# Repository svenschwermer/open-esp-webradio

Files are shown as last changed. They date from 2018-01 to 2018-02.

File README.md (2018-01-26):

# Open ESP Webradio
This project aims to build a webradio based on the ESP8266. The goal is to make
it controllable via touchscreen.

_This respository and the entire project is very much work-in-progress…_

## Hardware
The incoming encoded audio stream is buffered in an external SPI RAM. The ESP8266
has two hardware SPI controllers: SPI0 (aka SPI) and SPI1 (aka HSPI). The ESP-12F
module that is used here uses SPI0 for accessing the SPI flash memory that holds
the program data. Here, HSPI is used for accessing the SPI RAM. Since the pins
that are regularly used for HSPI will be used for talking I2S to the audio DAC,
SPI0 and HSPI are configured in overlap mode. That means, that they share the same
pins (except for the CS line). There is an arbiter that selects which SPI controller
gets to access the pins. The SPI RAM device here is a 23LC1024 which has a capacity
of 1 Mbit. Both the ESP8266 and the 23LC1024 support Quad SPI where all data lines
(SIO0..3) are bidirectional, so 4 bits are transferred in every clock cycle.

The audio DAC that is used here is the WM8731. The audio data is transferred using
I2S via the I2S controller that is built into the ESP8266. The configuration of
the DAC is performed via I2C. Even though the ESP8266 contains an I2C controller,
it is not used here, because the pins were not available. Since the WM8731 comes
with a microphone interface, it is included together with the reverse I2S direction.

The display that is used here, is a MI0283QT 240x320 color LCD. Infos about the
adapter board that molds a touchscreen controller as well, can be found
[here](https://github.com/watterott/MI0283QT-Adapter). Both the LCD controller and
the touchscreen controller are also sharing the same SPI pins as the SPI flash and
the SPI RAM. Both are controlled by the HSPI controller. The LCD uses a hardware
CS, but for the touchscreen controller, there was no more hardware CS available
that is not used for anything else. Hence, GPIO16 is used as the CS line for the
touchscreen controller.

### Schematic
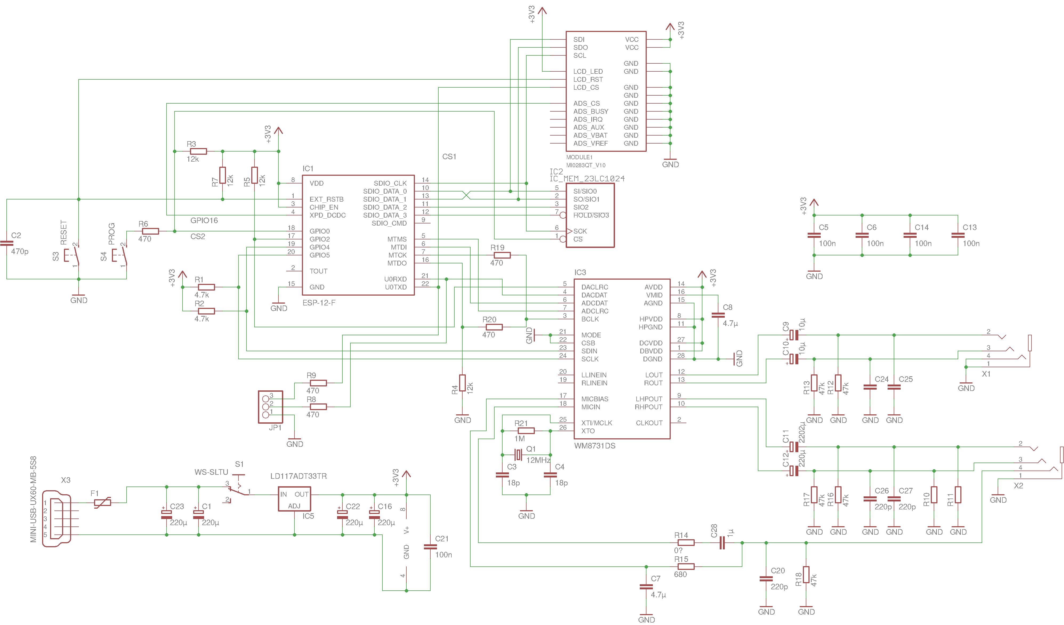
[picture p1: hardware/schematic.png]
MI0283QT-Adapter


#### Remarks
- The SPI RAM is wired incorrectly: SIO2 and SIO3 should be swapped. This is
  fixed in software.

## Software
To build the software, follow the instructions in the
[open-esp-webradio repository](https://github.com/SuperHouse/esp-open-rtos) to
install the required toolchain. Then simply run `make` or `make flash`,
respectively, to compile or flash the image. The WiFi credentials should be
supplied via the file `./esp-open-rtos/include/private_ssid_config.h`.

## Credits
Inspired by [ESP8266_MP3_DECODER](https://github.com/espressif/ESP8266_MP3_DECODER),
this project builds upon the following components:
- [open-esp-webradio](https://github.com/SuperHouse/esp-open-rtos)
- [libmad](https://www.underbit.com/products/mad)

## License
This project is licensed under the terms of the GNU GPLv3, see [LICENSE.md](LICENSE.md).

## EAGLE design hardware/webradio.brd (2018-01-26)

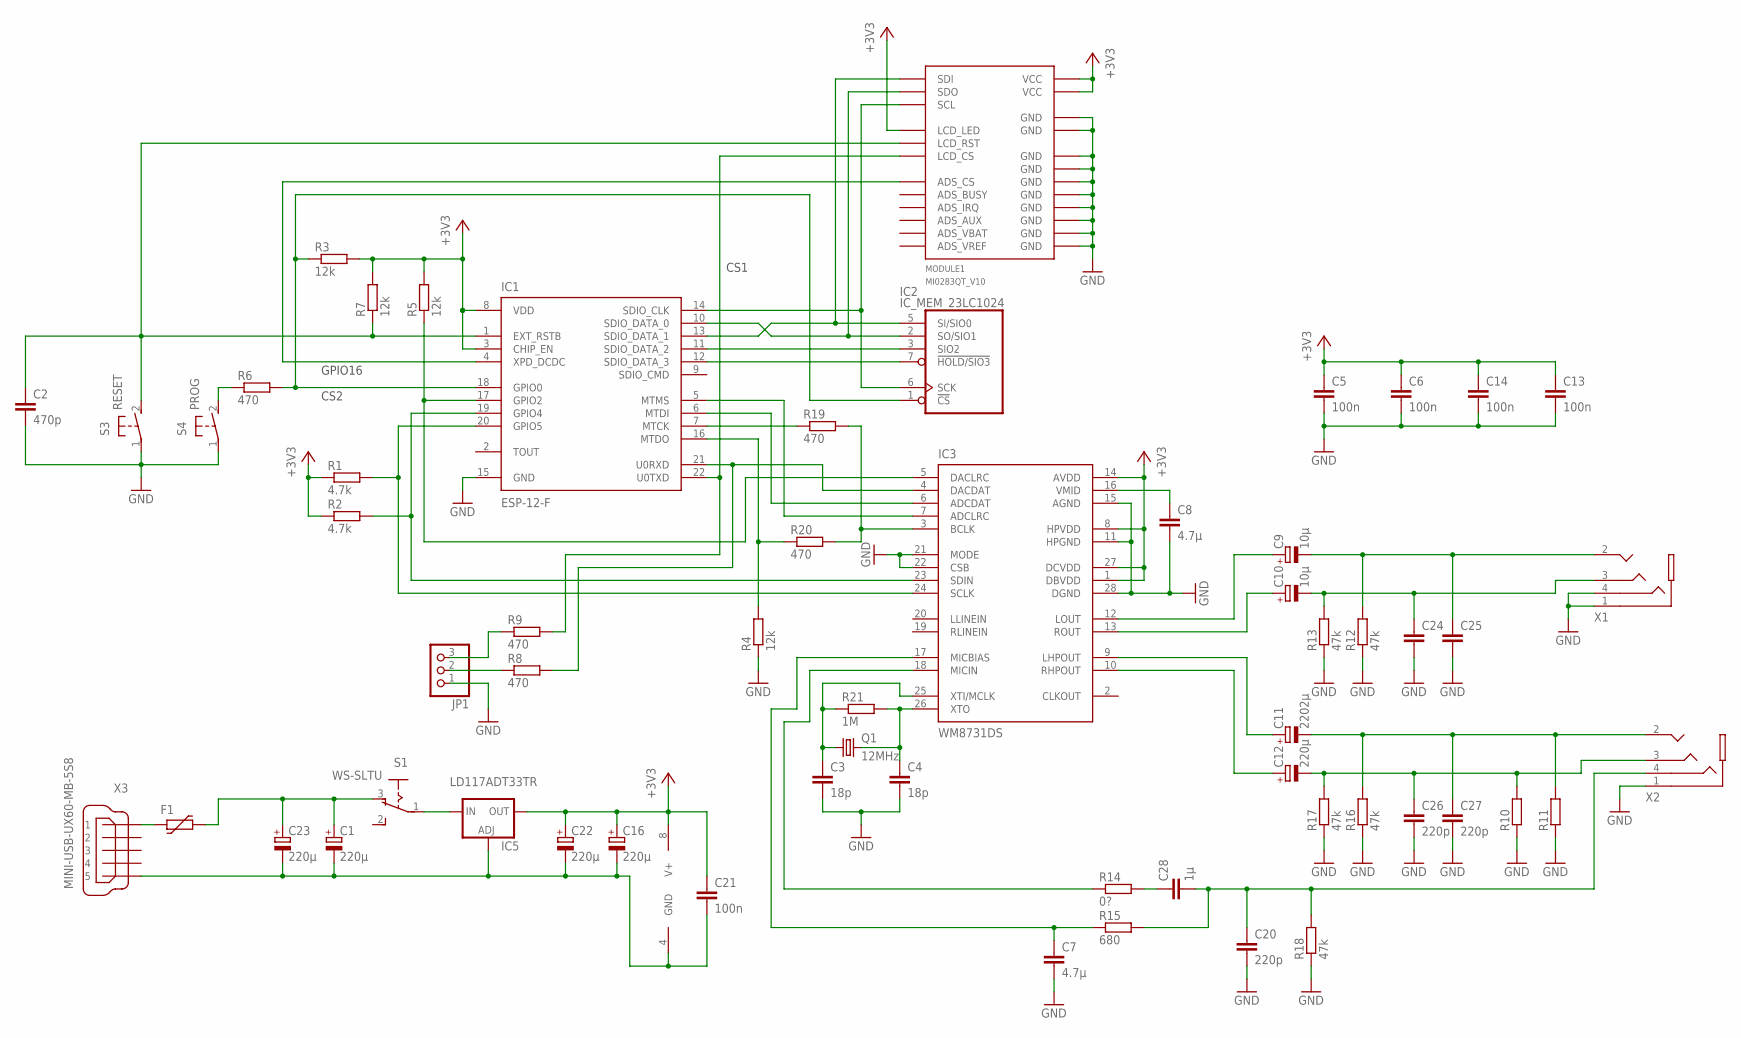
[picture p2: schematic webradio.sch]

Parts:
C1, C16, C22, C23: 220µ; B/3528-21R
C2: 470p; C0805
C3, C4: 18p; C0805
C5, C6, C13, C14, C21: 100n; C0805
C7, C8: 4.7µ; C0805
C9, C10: 10µ; A/3216-18R
C11: 2202µ; D/7343-31R
C12: 220µ; D/7343-31R
C20, C26, C27: 220p; C0805
C24, C25: C-EUC0805; C0805
C28: 1µ; C0805
F1: FUSE_PTC-1812; PTC1812L
IC1: ESP-12-F
IC2: IC_MEM_23LC1024; SOIC-8
IC3: WM8731DS; SSOP28
IC5: LD117ADT33TR; DPACK
JP1: PINHD-1X3/90; 1X03/90
MODULE1: MI0283QT_V10
Q1: 12MHz; HC49UP
R1, R2: 4.7k; R0805
R3, R4, R5, R7: 12k; R0805
R6, R8, R9, R19, R20: 470; R0805
R10, R11: R-EU_R0805; R0805
R12, R13, R16, R17, R18: 47k; R0805
R14: 0?; R0805
R15: 680; R0805
R21: 1M; R0805
S1: WS-SLTU; 450302014072
S3: RESET; B3F-31XX
S4: PROG; B3F-31XX
X1, X2: SJ-43514-SMT
X3: MINI-USB-UX60-MB-5S8; UX60-MB-5S8

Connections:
+3V3: C5.1, C6.1, C13.1, C14.1, C16.+, C21.1, C22.+, IC1.3 (CHIP_EN), IC1.8 (VDD), IC2.8 (V+), IC3.1 (DBVDD), IC3.8 (HPVDD), IC3.14 (AVDD), IC3.27 (DCVDD), IC5.4 (OUT), MODULE1.3_VCC (VCC), MODULE1.4_VCC (VCC), MODULE1.5_LCD_LED (LCD_LED), R1.1, R2.1, R3.2, R5.2, R7.2
GND: C1.-, C2.2, C3.2, C4.2, C5.2, C6.2, C7.2, C8.2, C13.2, C14.2, C16.-, C20.2, C21.2, C22.-, C23.-, C24.2, C25.2, C26.2, C27.2, IC1.15 (GND), IC2.4 (GND), IC3.11 (HPGND), IC3.15 (AGND), IC3.21 (MODE), IC3.22 (CSB), IC3.28 (DGND), IC5.1 (ADJ), JP1.1, MODULE1.1_GND (GND), MODULE1.2_GND (GND), MODULE1.GND_1 (GND), MODULE1.GND_2 (GND), MODULE1.GND_3 (GND), MODULE1.GND_4 (GND), MODULE1.GND_5 (GND), MODULE1.GND_6 (GND), MODULE1.GND_7 (GND), MODULE1.GND_8 (GND), R4.1, R10.1, R11.1, R12.1, R13.1, R16.1, R17.1, R18.1, S3.1, S4.1, X1.1, X1.4, X2.1, X3.5
unnamed: IC1.14 (SDIO_CLK), IC2.6 (SCK), MODULE1.10_SCL (SCL)
unnamed: IC1.18 (GPIO0), IC2.1 (!CS), R3.1, R6.2
unnamed: F1.1, X3.1
unnamed: IC1.10 (SDIO_DATA_0), IC2.2 (SO/SIO1), MODULE1.9_SDO (SDO)
unnamed: IC1.11 (SDIO_DATA_2), IC2.3 (SIO2)
unnamed: IC1.12 (SDIO_DATA_3), IC2.7 (!HOLD/SIO3)
unnamed: IC1.16 (MTDO), R4.2, R20.1
unnamed: IC1.21 (U0RXD), IC3.4 (DACDAT), R8.2
unnamed: IC1.17 (GPIO2), IC3.5 (DACLRC), R5.1
unnamed: IC1.19 (GPIO4), IC3.23 (SDIN), R2.2
unnamed: IC1.20 (GPIO5), IC3.24 (SCLK), R1.2
unnamed: R6.1, S4.2 (S)
unnamed: JP1.2, R8.1
unnamed: C2.1, IC1.1 (EXT_RSTB), MODULE1.6_LCD_RST (LCD_RST), R7.1, S3.2 (S)
unnamed: IC1.22 (U0TXD), MODULE1.7_LCD_CS (LCD_CS), R9.2
unnamed: JP1.3, R9.1
unnamed: C3.1, IC3.25 (XTI/MCLK), Q1.1, R21.1
unnamed: C4.1, IC3.26 (XTO), Q1.2, R21.2
unnamed: C1.+, C23.+, F1.2, S1.3 (O)
unnamed: C8.1, IC3.16 (VMID)
unnamed: C10.+, IC3.13 (ROUT)
unnamed: C9.+, IC3.12 (LOUT)
unnamed: C9.-, C25.1, R12.2, X1.2
unnamed: C10.-, C24.1, R13.2, X1.3
unnamed: C12.+, IC3.10 (RHPOUT)
unnamed: C11.+, IC3.9 (LHPOUT)
unnamed: C11.-, C27.1, R11.2, R16.2, X2.2
unnamed: C12.-, C26.1, R10.2, R17.2, X2.3
unnamed: IC5.3 (IN), S1.1
unnamed: C7.1, IC3.17 (MICBIAS), R15.1
unnamed: IC3.18 (MICIN), R14.1
unnamed: C28.1, R14.2
unnamed: C20.1, C28.2, R15.2, R18.2, X2.4
unnamed: IC1.6 (MTDI), IC3.6 (ADCDAT)
unnamed: IC1.5 (MTMS), IC3.7 (ADCLRC)
unnamed: IC1.7 (MTCK), R19.1
unnamed: IC3.3 (BCLK), R19.2, R20.2
unnamed: IC1.13 (SDIO_DATA_1), IC2.5 (SI/SIO0), MODULE1.8_SDI (SDI)
unnamed: IC1.4 (XPD_DCDC), MODULE1.11_ADS_CS (ADS_CS)

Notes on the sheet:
CS1
CS2
GPIO16

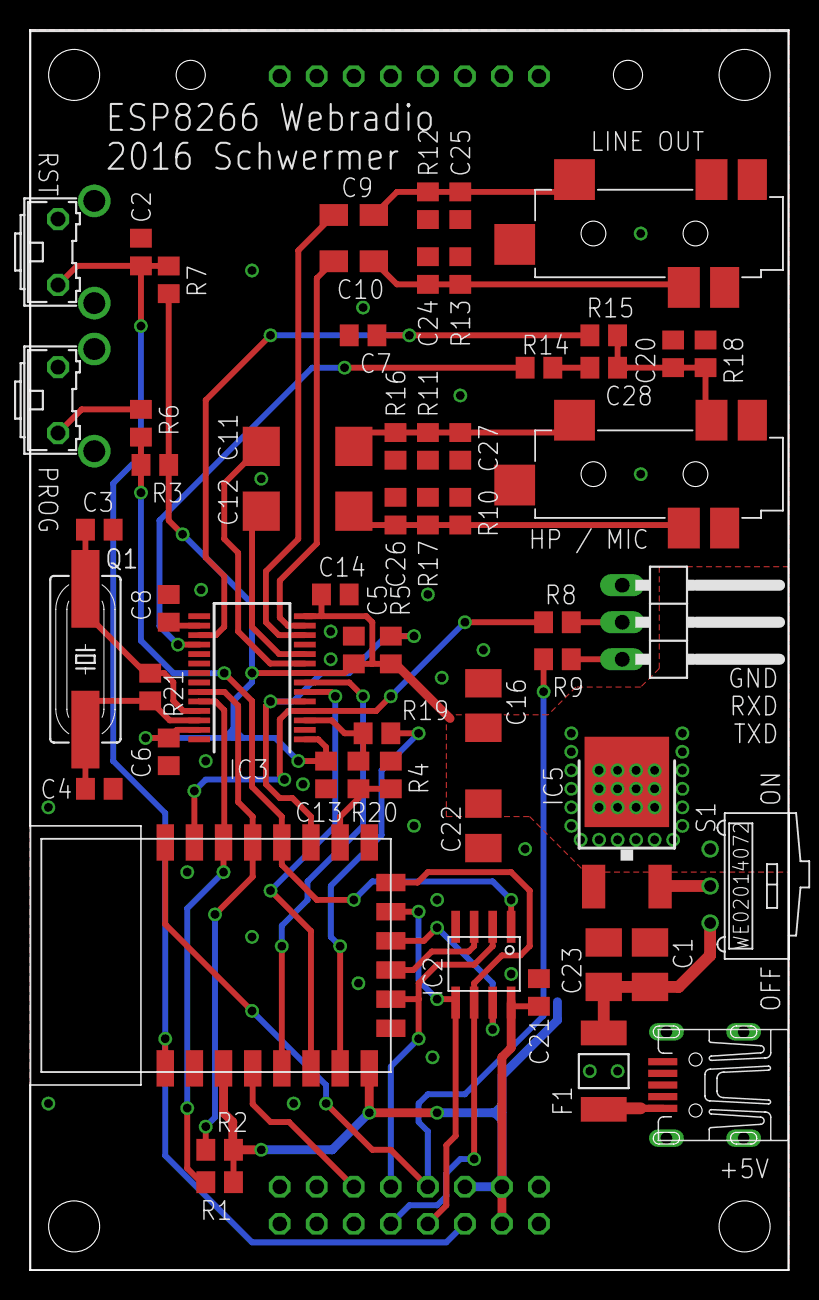
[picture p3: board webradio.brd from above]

Board: 2 copper layers, 52.1 x 85.1 mm, 59 parts (0 on the bottom side), 41 nets.

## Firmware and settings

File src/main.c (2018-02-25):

#include "fifo.h"
#include "mi0283qt.h"
#include "mp3.h"
#include "stream_client.h"
#include "terminal.h"
#include "wm8731.h"

#include "esp/hwrand.h"
#include "esp/uart.h"
#include "esp8266.h"
#include "espressif/esp_common.h"
#include "ssid_config.h"

#include "FreeRTOS.h"
#include "queue.h"
#include "task.h"
#include "timers.h"

#include <stdio.h>
#include <string.h>

void ui_task(void *p) {
  for (int i = 0;; ++i) {
#if 0
    printf("free heap: %u\nfifo: %u/%u\nunderruns: %u\n\n",
           xPortGetFreeHeapSize(), fifo_fill(), fifo_size(),
           get_and_reset_underrun_counter());
#endif
    vTaskDelay(2000 / portTICK_PERIOD_MS);
  }

  vTaskDelete(NULL);
}

static void stream_up(void) {
  if (xTaskCreate(mp3_task, "decode", 2100, NULL, 4, NULL) != pdPASS) {
    printf("Failed to create mp3 task!\n");
  }
}

static void stream_metadata(enum stream_metadata type, const char *s) {
  switch (type) {
  case STREAM_ARTIST:
    printf("Artist: %s\n", s);
    break;
  case STREAM_TITLE:
    printf("Title: %s\n", s);
    break;
  }
}

void user_init(void) {
  int ret;

  uart_set_baud(0, 115200);

  if ((ret = lcd_init())) {
    printf("lcd_init failed (%d)\n", ret);
    goto fail;
  }
  term_init();

  if ((ret = fifo_init())) {
    printf("fifo_init failed (%d)\n", ret);
    goto fail;
  }

  if ((ret = wm8731_init())) {
    printf("wm8731_init failed (%d)\n", ret);
    goto fail;
  }

  struct sdk_station_config config = {
      .ssid = WIFI_SSID,
      .password = WIFI_PASS,
  };

  /* required to call wifi_set_opmode before station_set_config */
  sdk_wifi_set_opmode(STATION_MODE);
  sdk_wifi_station_set_config(&config);

  if (stream_start("r.ezbt.me", "/antenne", stream_up, stream_metadata)) {
    printf("Failed to create stream task!\n");
    goto fail;
  }

  if (xTaskCreate(ui_task, "UI", configMINIMAL_STACK_SIZE, NULL, 1, NULL) !=
      pdPASS) {
    printf("Failed to create UI task!\n");
    goto fail;
  }

  return;

fail:
  while (1)
    ;
}

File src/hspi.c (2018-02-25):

#include "hspi.h"
#include "common.h"
#include "espressif/esp8266/esp8266.h"
#include "espressif/esp_common.h"

struct spi_regs {
  uint32_t cmd;       // 0x00
  uint32_t addr;      // 0x04
  uint32_t ctrl;      // 0x08
  uint32_t ctrl1;     // 0x0c
  uint32_t rd_status; // 0x10
  uint32_t ctrl2;     // 0x14
  uint32_t clock;     // 0x18
  uint32_t user;      // 0x1c
  uint32_t user1;     // 0x20
  uint32_t user2;     // 0x24
  uint32_t wr_status; // 0x28
  uint32_t pin;       // 0x2c
  uint32_t slave;     // 0x30
  uint32_t slave1;    // 0x34
  uint32_t slave2;    // 0x38
  uint32_t slave3;    // 0x3c
  uint32_t w[16];     // 0x40..0x7c
  uint32_t _[28];     // 0x80..0xec
  uint32_t ext0;      // 0xf0
  uint32_t ext1;      // 0xf4
  uint32_t ext2;      // 0xf8
  uint32_t ext3;      // 0xfc
};

static void apply_settings(struct hspi *hspi, uint32_t user_reg);

// The following SPI controller instances are located using the linker script.
extern volatile struct spi_regs SPI;  // aka SPI0, used for the flash mememry
extern volatile struct spi_regs HSPI; // aka SPI1

int hspi_init(struct hspi *settings) {
  switch (settings->mode) {
  case SPI_MODE_SPI:
  case SPI_MODE_DIO:
  case SPI_MODE_QIO:
    break;
  default:
    return 1;
  }

  switch (settings->cs) {
  case 0:
    PIN_FUNC_SELECT(PERIPHS_IO_MUX_SD_CMD_U, FUNC_SPICS0);
    break;
  case 1:
    PIN_FUNC_SELECT(PERIPHS_IO_MUX_U0TXD_U, FUNC_SPICS1);
    break;
  case 2:
    PIN_FUNC_SELECT(PERIPHS_IO_MUX_GPIO0_U, FUNC_SPICS2);
    break;
  default:
    return 1;
  }

  if (settings->clock_div < 1 || settings->clock_div > 64)
    return 1;

  // hspi overlap to spi, two spi masters on cspi
  SET_PERI_REG_MASK(HOST_INF_SEL, PERI_IO_CSPI_OVERLAP);

  // set higher priority for spi than hspi
  SPI.ext3 |= 0x1;
  HSPI.ext3 |= 0x3;

  return 0;
}

size_t hspi_read(struct hspi *settings, size_t len, void *data, int addr_bits,
                 uint32_t addr, int cmd_bits, uint16_t cmd, int dummy_cycles) {
  // we can read a maximum of 16*4=64 bytes at a time
  if (len > 64)
    len = 64;

  uint32_t user_reg = SPI_CS_SETUP | SPI_CS_HOLD | SPI_USR_MISO | SPI_CK_I_EDGE;
  uint32_t user1_reg = ((8 * len) - 1) << SPI_USR_MISO_BITLEN_S;
  if (cmd_bits > 0)
    user_reg |= SPI_USR_COMMAND;
  if (addr_bits > 0) {
    user_reg |= SPI_USR_ADDR;
    user1_reg |= (min(addr_bits, 32) - 1) << SPI_USR_ADDR_BITLEN_S;
  }
  if (dummy_cycles > 0) {
    user_reg |= SPI_USR_DUMMY;
    user1_reg |= (min(dummy_cycles, 256) - 1) << SPI_USR_DUMMY_CYCLELEN_S;
  }

  // make sure the last operation is done
  while (HSPI.cmd & SPI_USR)
    ;

  apply_settings(settings, user_reg);

  HSPI.user1 = user1_reg;
  if (cmd_bits > 0)
    HSPI.user2 = ((min(cmd_bits, 16) - 1) << SPI_USR_COMMAND_BITLEN_S) | cmd;
  if (addr_bits > 0)
    HSPI.addr = addr << (32 - addr_bits);

  // start data transfer and wait until completion
  HSPI.cmd |= SPI_USR;
  while (HSPI.cmd & SPI_USR)
    ;

  if (((uintptr_t)data) & 0x3 || len % 4 != 0) {
    uint8_t *byte_buf = data;
    for (size_t i = 0; i < len;) {
      uint32_t d = HSPI.w[i / 4];
      byte_buf[i++] = d & 0xff;
      if (i < len)
        byte_buf[i++] = (d >> 8) & 0xff;
      if (i < len)
        byte_buf[i++] = (d >> 16) & 0xff;
      if (i < len)
        byte_buf[i++] = (d >> 24) & 0xff;
    }
  } else {
    uint32_t *word_buf = data;
    for (size_t i = 0; i < len / 4; ++i)
      word_buf[i] = HSPI.w[i];
  }

  return len;
}

size_t hspi_write(struct hspi *settings, size_t len, const void *data,
                  int addr_bits, uint32_t addr, int cmd_bits, uint16_t cmd) {
  // we can write a maximum of 16*4=64 bytes at a time
  if (len > 64)
    len = 64;
  if (addr_bits > 32)
    addr_bits = 32;
  if (cmd_bits > 16)
    cmd_bits = 16;

  uint32_t user_reg = SPI_CS_SETUP | SPI_CS_HOLD | SPI_CK_I_EDGE;
  if (cmd_bits > 0)
    user_reg |= SPI_USR_COMMAND;
  if (len > 0)
    user_reg |= SPI_USR_MOSI;
  if (addr_bits > 0)
    user_reg |= SPI_USR_ADDR;

  // make sure the last operation is done
  while (HSPI.cmd & SPI_USR)
    ;

  apply_settings(settings, user_reg);

  if (addr_bits > 0 || len > 0)
    HSPI.user1 = (((8 * len) - 1) << SPI_USR_MOSI_BITLEN_S) |
                 ((addr_bits - 1) << SPI_USR_ADDR_BITLEN_S);
  if (cmd_bits > 0)
    HSPI.user2 = ((cmd_bits - 1) << SPI_USR_COMMAND_BITLEN_S) | cmd;
  if (addr_bits > 0)
    HSPI.addr = addr << (32 - addr_bits);

  if (((uintptr_t)data) & 0x3 || len % 4 != 0) {
    const uint8_t *byte_buf = data;
    for (size_t i = 0; i < len;) {
      uint32_t d = byte_buf[i++];
      if (i < len)
        d |= ((uint32_t)byte_buf[i++]) << 8;
      if (i < len)
        d |= ((uint32_t)byte_buf[i++]) << 16;
      if (i < len)
        d |= ((uint32_t)byte_buf[i++]) << 24;
      HSPI.w[(i - 1) / 4] = d;
    }
  } else {
    const uint32_t *word_buf = data;
    for (size_t i = 0; i < len / 4; ++i)
      HSPI.w[i] = word_buf[i];
  }

  // start data transfer
  HSPI.cmd |= SPI_USR;

  return len;
}

static void apply_settings(struct hspi *settings, uint32_t user_reg) {
  static const uint32_t ctrl_mask = SPI_QIO_MODE | SPI_DIO_MODE;
  static const uint32_t user_mask = SPI_FWRITE_QIO | SPI_FWRITE_DIO;
  static const uint32_t cs_mask = SPI_CS0_DIS | SPI_CS1_DIS | SPI_CS2_DIS;

  switch (settings->mode) {
  case SPI_MODE_SPI:
    HSPI.ctrl &= ~ctrl_mask;
    HSPI.user = user_reg & ~user_mask;
    break;
  case SPI_MODE_DIO:
    HSPI.ctrl = (HSPI.ctrl & ~ctrl_mask) | SPI_DIO_MODE;
    HSPI.user = (user_reg & ~user_mask) | SPI_FWRITE_DIO;
    break;
  case SPI_MODE_QIO:
    HSPI.ctrl = (HSPI.ctrl & ~ctrl_mask) | SPI_QIO_MODE;
    HSPI.user = (user_reg & ~user_mask) | SPI_FWRITE_QIO;
    break;
  }

  switch (settings->cs) {
  case 0:
    HSPI.pin = (HSPI.pin & ~cs_mask) | SPI_CS1_DIS | SPI_CS2_DIS;
    break;
  case 1:
    HSPI.pin = (HSPI.pin & ~cs_mask) | SPI_CS0_DIS | SPI_CS2_DIS;
    break;
  case 2:
    HSPI.pin = (HSPI.pin & ~cs_mask) | SPI_CS0_DIS | SPI_CS1_DIS;
    break;
  }

  const uint32_t clkcnt_n = settings->clock_div - 1;
  const uint32_t clkcnt_h = settings->clock_div / 2 - 1;
  HSPI.clock = (clkcnt_n << SPI_CLKCNT_N_S) | (clkcnt_h << SPI_CLKCNT_H_S) |
               (clkcnt_n << SPI_CLKCNT_L_S);
}

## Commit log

2017-11-05 Working SPI RAM based FIFO
2017-11-11 At least we're getting some noise
    [wm8731.c]
2017-11-25 Fix SPIRAM reliability issues
    Force the RAM into sequential mode upon bootup.
    [fifo.c, spiram.c]
2017-11-26 Working state for regular (non-QIO) SPI
2017-11-26 Complete SPI register definition
2017-11-26 Allow different SPI users to use different clocks
2017-11-27 Refactor SPI instances
2018-01-16 Increase mp3 decoder prio to avoid underruns
    [main.c]
2018-01-19 Rework terminal
    Allow successive printf calls to print to the same line. Remove mutex from terminal code, as it seems to be redundant.
2018-01-19 Print periodic status info
2018-01-26 Add readme and schematic
2018-01-26 Add Eagle schematic and board design
    [webradio.brd, webradio.sch]
2018-01-28 Change sample rate based on mp3 frame
